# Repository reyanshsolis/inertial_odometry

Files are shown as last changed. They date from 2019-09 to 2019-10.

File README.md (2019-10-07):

# AGV_Encoders_IMU

# Project Goal

To develope accurate and precise encoders using two Innertial Mesurement Units

# Components Used

1. IMU
2. Communication Modules(XBEE or NRF)
3. Arduino Nano
4. Arduino Mega
5. 9V Battery

# Description

This paper describes the design and development of a non-intrusive inertial sensor used for determining the odometry of a ground vehicle. The sensors are meant to be placed on the rim of the wheels of a ground vehicle and determine the angular velocity of wheels and the angular velocity of the vehicle about its center axis perpendicular to the ground plane. The mathematical model incorporates the electronic gyroscope data of left and right wheel sensor and the relationship between the angular velocity about the central axis of wheels on either side while turning, to calculate the turning angular velocity of car and angular velocities of wheels which in turn determines the linear velocity of the car. These sensors can be used to replace the conventional optical or hall-effect based speed sensors which are difficult to be used with existing models of the ground vehicle as they require specific placement and specially designed mounts. 
The primary advantage of this sensor is that it can be placed at any position on the wheel, at any angle with respect to the wheel plane. The determined parameters do not depend on the placement of the sensor on the wheel in any way, as it only requires the resultant of angular velocities on each tire. Multiple noises and bias filters such as Kalman Filter for bias reduction and Extended Kalman Filter and Madgwick Filter among others for noise reduction have been tested on this model and the obtained results have been compared and analyzed in this paper with respect to the quality of the output, computation time and resultant lag.
Different modules for wireless communication (nrf24l01+, Zigbee Xbee S2C) were also used for obtaining the best performance for this specific purpose and the results have been analyzed in terms of data rate, range and security, and reliability among others. This sensor has been tested on different types of vehicles such as cars, rickshaws and mobile robots such as Husky and Jackal under varying road conditions and the performance was compared with optical encoders that are currently being used for odometry estimation.

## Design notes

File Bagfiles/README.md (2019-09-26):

# inertial_odometry
Non-Intrusive Inertial Based Sensor for Odometry of Ground Vehicle

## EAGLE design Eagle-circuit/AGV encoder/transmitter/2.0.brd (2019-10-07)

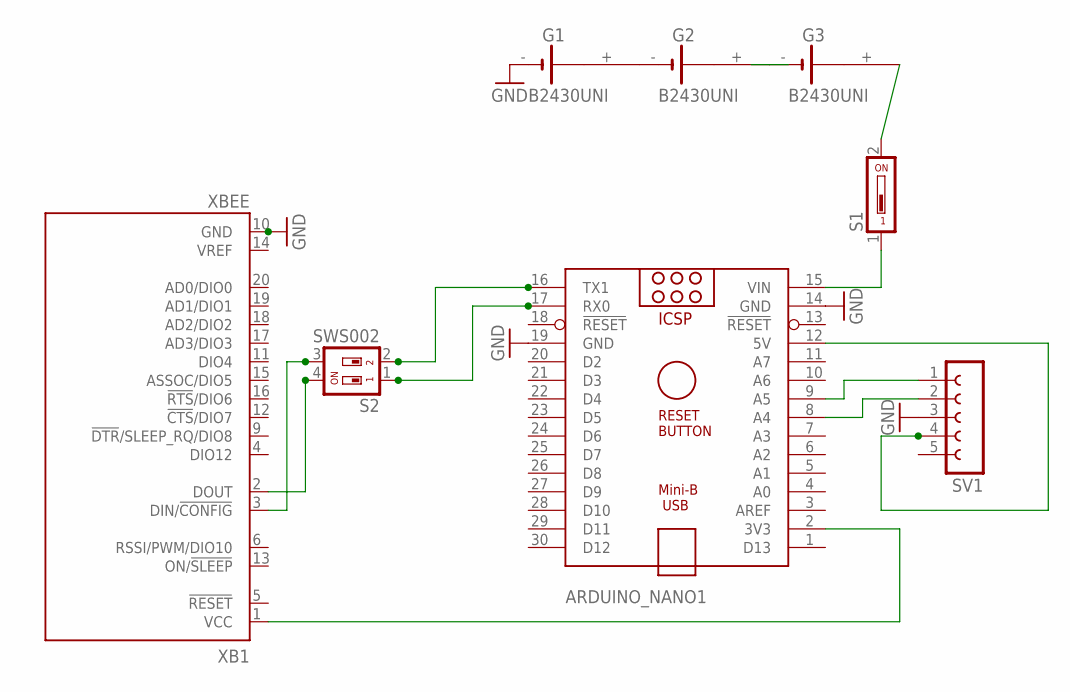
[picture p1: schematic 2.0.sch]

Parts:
ARDUINO_NANO1: ARDUINO_NANO
G1, G2, G3: B2430UNI
S1: DS01; DS-01
S2: SWS002; SMS-002
SV1: FE05-1
XB1: XBEE

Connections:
GND: ARDUINO_NANO1.14 (GND), ARDUINO_NANO1.19 (GND), G1.-, SV1.3, XB1.10 (GND)
unnamed: G1.+, G2.-
unnamed: G2.+@1 (+), G3.-
unnamed: G2.+, G3.-@1 (-)
unnamed: G3.+, S1.2
unnamed: ARDUINO_NANO1.15 (VIN), S1.1
unnamed: S2.4, XB1.2 (DOUT)
unnamed: ARDUINO_NANO1.17 (RX0), S2.1
unnamed: ARDUINO_NANO1.16 (TX1), S2.2
unnamed: S2.3, XB1.3 (DIN/!CONFIG)
unnamed: ARDUINO_NANO1.2 (3V3), XB1.1 (VCC)
unnamed: ARDUINO_NANO1.9 (A5), SV1.1
unnamed: ARDUINO_NANO1.8 (A4), SV1.2
unnamed: ARDUINO_NANO1.12 (5V), SV1.4

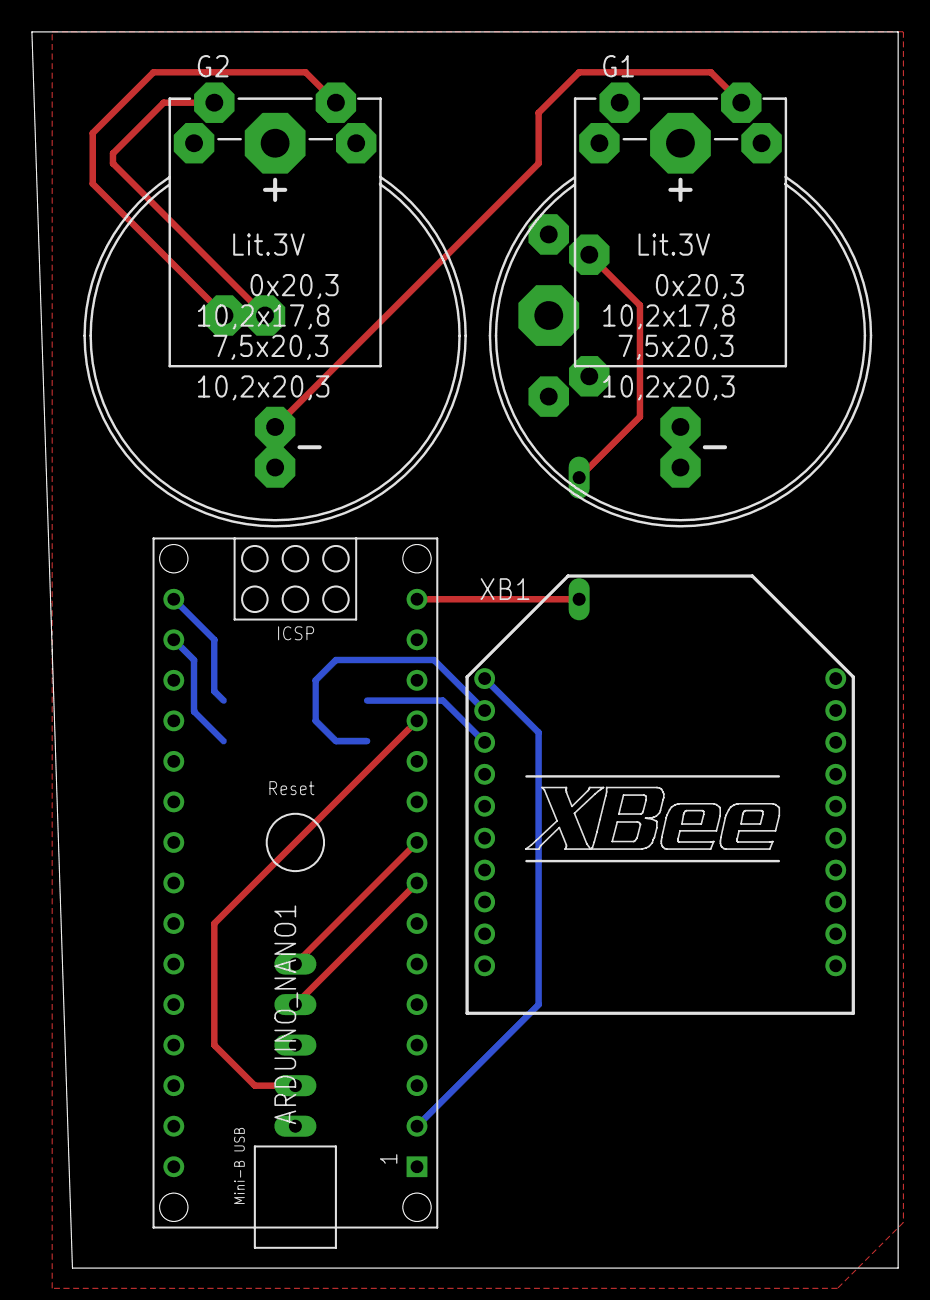
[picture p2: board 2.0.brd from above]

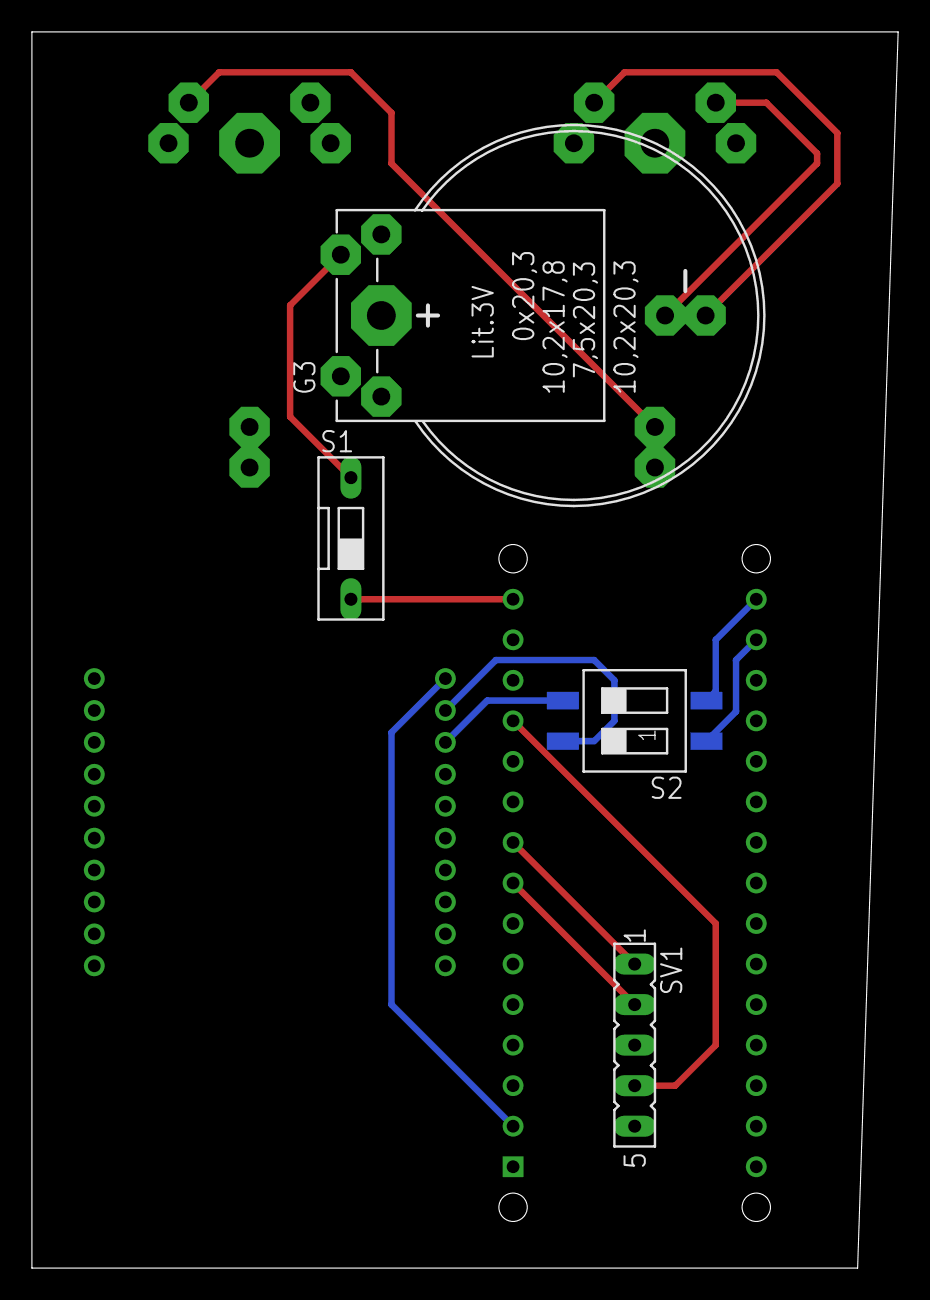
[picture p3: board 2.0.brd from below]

Board: 2 copper layers, 54.3 x 77.5 mm, 8 parts (4 on the bottom side), 14 nets.

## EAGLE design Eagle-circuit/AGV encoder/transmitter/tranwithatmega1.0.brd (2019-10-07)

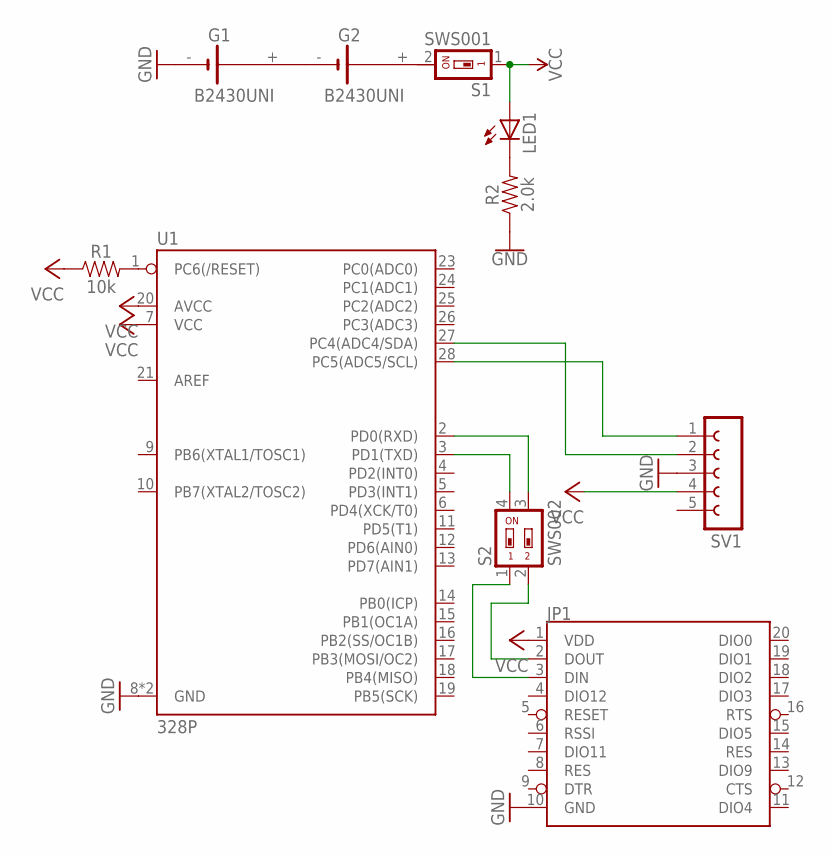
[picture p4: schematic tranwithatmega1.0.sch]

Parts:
G1, G2: B2430UNI
JP1: XBEE
LED1: LED_E; LED_1206
R1: 10k; AXIAL-0.3
R2: 2.0k; 0603
S1: SWS001; SMS-001
S2: SWS002; SMS-002
SV1: FE05-1
U1: 328P; DIP28

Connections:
GND: G1.-, JP1.10 (GND), R2.1, SV1.3, U1.8 (GND), U1.22 (GND)
unnamed: R1.P$2 (2), U1.1 (PC6(/RESET))
unnamed: SV1.1, U1.28 (PC5(ADC5/SCL))
unnamed: SV1.2, U1.27 (PC4(ADC4/SDA))
unnamed: S2.3, U1.2 (PD0(RXD))
unnamed: JP1.3 (DIN), S2.1
unnamed: G1.+, G2.-
unnamed: G2.+@1 (+), S1.2
unnamed: S2.4, U1.3 (PD1(TXD))
unnamed: JP1.2 (DOUT), S2.2
unnamed: LED1.C, R2.2
VCC: JP1.1 (VDD), LED1.A, R1.P$1 (1), S1.1, SV1.4, U1.7 (VCC), U1.20 (AVCC)

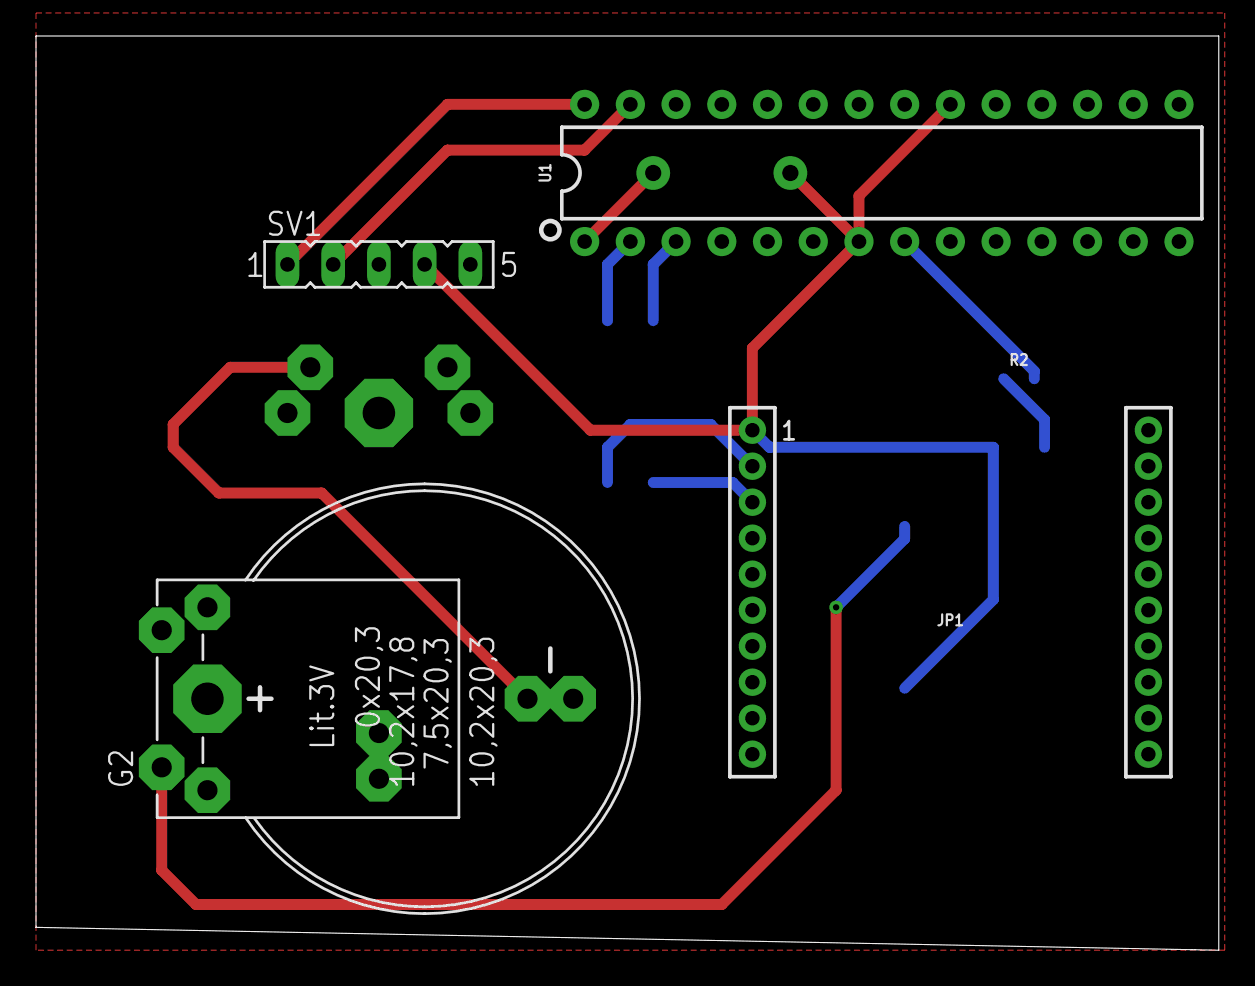
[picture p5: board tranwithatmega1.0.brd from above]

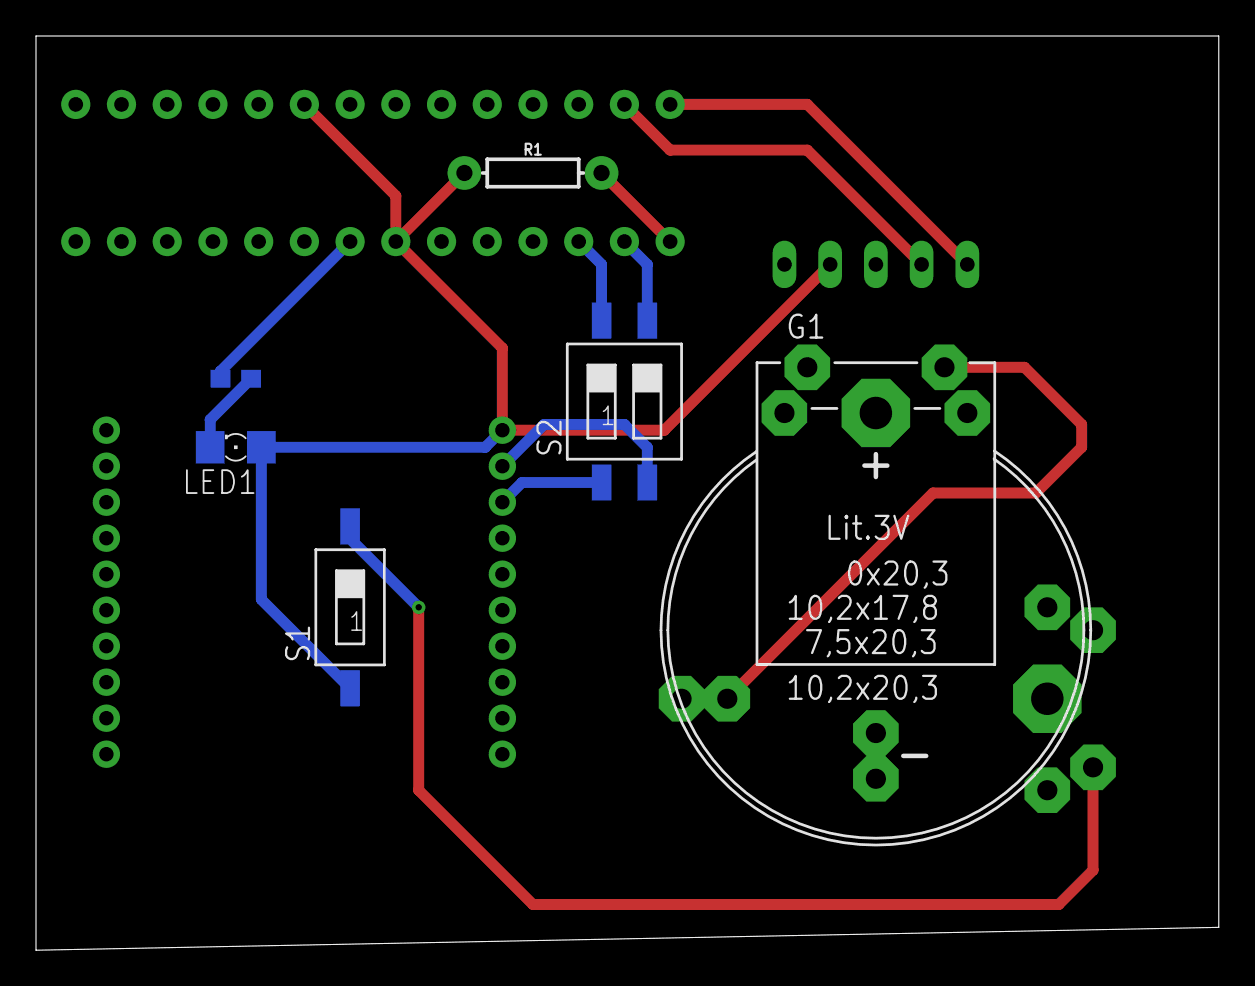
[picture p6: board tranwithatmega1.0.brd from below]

Board: 2 copper layers, 65.7 x 50.8 mm, 10 parts (6 on the bottom side), 12 nets.

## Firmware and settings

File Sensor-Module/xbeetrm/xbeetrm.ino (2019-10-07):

// Keep the circuit stable on a surface for atleast 10 seconds to set offset
// enc_trans03_r - transmits RAW data from IMU : ax ay az gx gy gz dc_offset 
// LEFT SIDE WHEEL

//SDA=A4
//SCL=A5


#include <Wire.h>  
#include <LSM6.h>
#include <SPI.h>
#include <XBee.h>


LSM6 imu;

long int sampleNum = 1000; 
float dc_offset = 0;
float dc_offset_x = 0;
float dc_offset_y = 0;
float dc_offset_z = 0;

char report[80];


XBee xbee = XBee();

uint8_t payload[] = { 0, 0, 0, 0};
int pin5 = 0;

int statusLed = 13;
int errorLed = 13;

// SH + SL Address of receiving XBee
XBeeAddress64 addr64 = XBeeAddress64(0x0013a200, 0x4189730b);
ZBTxRequest zbTx = ZBTxRequest(addr64, payload, sizeof(payload));
ZBTxStatusResponse txStatus = ZBTxStatusResponse();


void flashLed(int pin, int times, int wait) {

  for (int i = 0; i < times; i++) {
    digitalWrite(pin, HIGH);
    delay(wait);
    digitalWrite(pin, LOW);

    if (i + 1 < times) {
      delay(wait);
    }
  }
}




void setup() {

  delay(5000);
  
  pinMode(statusLed, OUTPUT);
  pinMode(errorLed, OUTPUT);

  Serial.begin(9600);
  xbee.setSerial(Serial);


  Wire.begin();
  Serial.println("Y"); //Code has started
  imu.init();
  if (!imu.init())
  {
    Serial.println("N"); // Failed to detect and initialize IMU!
    while (1);
  }
  
  imu.writeReg(LSM6::CTRL9_XL, 0x38);  // Acc X, Y, Z axes enabled
  imu.writeReg(LSM6::CTRL1_XL, 0x70);  // Acc = 833Hz (High-Performance mode)
  imu.writeReg(LSM6::INT1_CTRL, 0x01); // Acc Data Ready interrupt on INT1
  imu.writeReg(LSM6::CTRL10_C, 0x38);  // Gyro X, Y, Z axes enabled
  imu.writeReg(LSM6::CTRL2_G, 0x7C);   // Gyro = 833Hz (High-Performance mode) and 2000dps
  imu.writeReg(LSM6::INT2_CTRL, 0x02); // Gyro Data Ready interrupt on INT1
  
  for(int n=0;n<sampleNum;n++)
  { 
    imu.writeReg(LSM6::STATUS_REG, 0x0B); //this hex number represents the status register
    imu.read(); 
    snprintf(report, sizeof(report), "A: %6d %6d %6d    G: %6d %6d %6d", imu.a.x, imu.a.y, imu.a.z, imu.g.x, imu.g.y, imu.g.z);
    dc_offset_z += imu.g.z;
    dc_offset_y += imu.g.y;
    dc_offset_x += imu.g.x;
  } 
  
  dc_offset_z =dc_offset_z/sampleNum;  
  dc_offset_y =dc_offset_y/sampleNum;
  dc_offset_x =dc_offset_x/sampleNum;
  //Serial.println(dc_offset); 
  //Serial.print("#"); //indicates start of msg
}

void loop() {   


  //double aix, aiy, aiz;
  float gix, giy, giz, gi;
    
  imu.writeReg(LSM6::STATUS_REG, 0x0B); //this hex number represents the status register
  imu.read();
  snprintf(report, sizeof(report), "A: %6d %6d %6d    G: %6d %6d %6d", imu.a.x, imu.a.y, imu.a.z, imu.g.x, imu.g.y, imu.g.z);

  //aix = imu.a.x;
  //aiy = imu.a.y;
  //aiz = imu.a.z;

/* Conversion factor :   
 * since we are using 2000 degrees/seconds range
 * -2000 maps to a raw value of -32768
 * +2000 maps to a raw value of 32767
 * So, g(degree/sec.)=g(raw)*2000.0/32768.0
 * g(rpm)=g(degree/sec) /6    // rpm = (360degree)/(60sec) = (1/6)(degree/sec)
 * So, g(rpm) = 0.0101725 * g(raw)
 * 
 * for acc. : 
 * since we are using 2G range
 * -2g maps to a raw value of -32768
 * +2g maps to a raw value of 32767
 */

  gix = 0.0101725 * (imu.g.x - dc_offset_x);
  giy = 0.0101725 * (imu.g.y - dc_offset_y);
  giz = 0.0101725 * (imu.g.z - dc_offset_z);
  
  gi=sqrt(sq(gix)+sq(giy)+sq(giz));
//  Serial.print("%");
//  Serial.print(gi);   
//  Serial.print("%");

long int val=int(gi*10000);

  union {
      float f;
      byte b[4];
   } stuff;


payload[0] = byte(val >> 24 & 0xff);//stuff.b[0];
payload[1] = byte(val >> 16 & 0xff);//stuff.b[1];
payload[2] = byte(val >> 8 & 0xff);//stuff.b[2];
payload[3] = byte(val);//stuff.b[3];
//payload[4] = stuff.b[4];
//payload[5] = stuff.b[5];
//payload[6] = stuff.b[6];
//payload[7] = stuff.b[7];
  // break down 10-bit reading into two bytes and place in payload
//  pin5 = val;
//  payload[0] = pin5 >> 8 & 0xff;
//  payload[1] = pin5 & 0xff;
  Serial.print(payload[0]);
  Serial.print(payload[1]);
  Serial.print(payload[2]);
  Serial.print(payload[3]);
  xbee.send(zbTx);

  // flash TX indicator
  flashLed(statusLed, 1, 100);

  // after sending a tx request, we expect a status response
  // wait up to half second for the status response
  if (xbee.readPacket(500)) {
    // got a response!

    // should be a znet tx status              
    if (xbee.getResponse().getApiId() == ZB_TX_STATUS_RESPONSE) {
      xbee.getResponse().getZBTxStatusResponse(txStatus);

      // get the delivery status, the fifth byte
      if (txStatus.getDeliveryStatus() == SUCCESS) {
        // success.  time to celebrate
        flashLed(statusLed, 5, 50);
        
      } else {
        // the remote XBee did not receive our packet. is it powered on?
        flashLed(errorLed, 3, 500);
       
      }
    }
  } else if (xbee.getResponse().isError()) {
    //nss.print("Error reading packet.  Error code: ");  
    //nss.println(xbee.getResponse().getErrorCode());
  } else {
    // local XBee did not provide a timely TX Status Response -- should not happen
    flashLed(errorLed, 2, 50);
    
  }

//  delay(1000);
}

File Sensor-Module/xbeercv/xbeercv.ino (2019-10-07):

/**
 * Copyright (c) 2009 Andrew Rapp. All rights reserved.
 *
 * This file is part of XBee-Arduino.
 *
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
 * You should have received a copy of the GNU General Public License
 * along with XBee-Arduino.  If not, see <http://www.gnu.org/licenses/>.
 */

#include <XBee.h>

/*
This example is for Series 1 XBee (802.15.4)
Receives either a RX16 or RX64 packet and sets a PWM value based on packet data.
Error led is flashed if an unexpected packet is received
*/

XBee xbee = XBee();
XBeeResponse response = XBeeResponse();
// create reusable response objects for responses we expect to handle 
Rx16Response rx16 = Rx16Response();
Rx64Response rx64 = Rx64Response();
XBeeAddress64 adr64 = XBeeAddress64();
//ZBRxResponse adr16 = ZBRxResponse();

int statusLed = 11;
int errorLed = 12;
int dataLed = 10;

uint16_t add=1;

uint8_t option = 0;
uint8_t data = 0;

void flashLed(int pin, int times, int wait) {
    
    for (int i = 0; i < times; i++) {
      digitalWrite(pin, HIGH);
      delay(wait);
      digitalWrite(pin, LOW);
      
      if (i + 1 < times) {
        delay(wait);
      }
    }
}

 union {
      float f;
      byte b[4];
   } stuff;

void setup() {
  pinMode(statusLed, OUTPUT);
  pinMode(errorLed, OUTPUT);
  pinMode(dataLed,  OUTPUT);
  
  // start serial
  Serial.begin(9600);
  xbee.setSerial(Serial);
  
  flashLed(statusLed, 3, 50);
}

// continuously reads packets, looking for RX16 or RX64
void loop() {
    
    xbee.readPacket();
    
    if (xbee.getResponse().isAvailable()) {
      // got something
      adr64 = rx64.getRemoteAddress64();
      add = rx16.getRemoteAddress16();
      Serial.print("@"); 
      Serial.println(add);
      Serial.println(adr64.getLsb());
      if (xbee.getResponse().getApiId() == RX_16_RESPONSE || xbee.getResponse().getApiId() == RX_64_RESPONSE) {
        // got a rx packet
        
        if (xbee.getResponse().getApiId() == RX_16_RESPONSE) {
                xbee.getResponse().getRx16Response(rx16);
        	option = rx16.getOption();
        	//data = rx16.getData(0);
          stuff.b[0] = rx16.getData(0);
          stuff.b[1] = rx16.getData(1);
          stuff.b[2] = rx16.getData(2);
          stuff.b[3] = rx16.getData(3);
//          stuff.b[4] = rx16.getData(4);
//          stuff.b[5] = rx16.getData(5);
//          stuff.b[6] = rx16.getData(6);
//          stuff.b[7] = rx16.getData(7);
         Serial.write(stuff.b[0]);
         Serial.write(stuff.b[1]);
         Serial.write(stuff.b[2]);
         Serial.write(stuff.b[3]);
         Serial.println("");
         //Serial.print(stuff.f);
        } else {
                xbee.getResponse().getRx64Response(rx64);
        	option = rx64.getOption();
        	//data = rx64.getData(0);
          stuff.b[0] = rx64.getData(0);
          stuff.b[1] = rx64.getData(1);
          stuff.b[2] = rx64.getData(2);
          stuff.b[3] = rx64.getData(3);
//          stuff.b[4] = rx64.getData(4);
//          stuff.b[5] = rx64.getData(5);
//          stuff.b[6] = rx64.getData(6);
//          stuff.b[7] = rx64.getData(7);
         Serial.write(stuff.b[0]);
         Serial.write(stuff.b[1]);
         Serial.write(stuff.b[2]);
         Serial.write(stuff.b[3]);
         Serial.println("");
         //Serial.print(stuff.f);
        }
        
        // TODO check option, rssi bytes    
        flashLed(statusLed, 1, 10);
        
        // set dataLed PWM to value of the first byte in the data
        analogWrite(dataLed, data);
      } else {
      	// not something we were expecting
        flashLed(errorLed, 1, 25);    
      }
    } else if (xbee.getResponse().isError()) {
      //nss.print("Error reading packet.  Error code: ");  
      //nss.println(xbee.getResponse().getErrorCode());
      // or flash error led
    } 
}

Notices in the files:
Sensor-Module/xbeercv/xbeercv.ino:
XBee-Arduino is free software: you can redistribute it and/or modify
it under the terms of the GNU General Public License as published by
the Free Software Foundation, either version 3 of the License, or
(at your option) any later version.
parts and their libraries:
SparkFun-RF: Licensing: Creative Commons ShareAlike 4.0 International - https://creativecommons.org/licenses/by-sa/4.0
